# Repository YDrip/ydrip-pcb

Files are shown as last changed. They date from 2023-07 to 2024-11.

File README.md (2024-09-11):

# Open-Source Water Meter Hardware Design

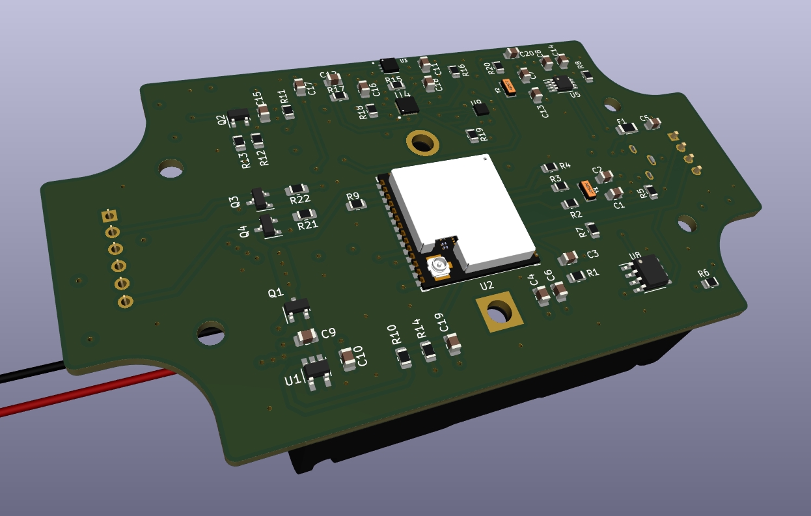
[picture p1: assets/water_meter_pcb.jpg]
PCB ICs

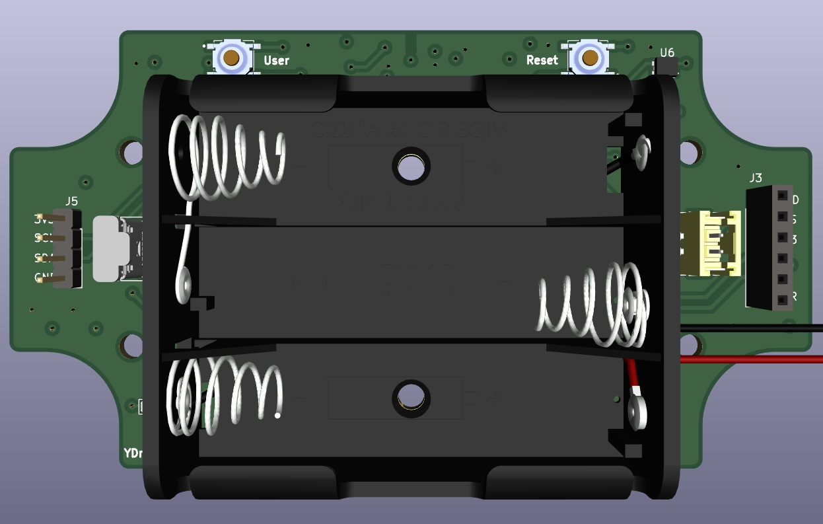
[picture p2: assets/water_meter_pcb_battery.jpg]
PCB Battery


## Description

This repository contains the open-source hardware design files for a water meter. The design was created using KiCad 6.

## Features

- High-precision water metering
- Low power consumption
- Compact and cost-effective design
- Compatible with standard water metering infrastructure
- Customizable digital logic

## Details

Panalization command

```bash
	kikit panelize \
	--layout 'grid; rows: 2; cols: 2; space: 2mm' \
	--tabs 'fixed; width: 8mm; vcount: 2; hcount: 1'\
	--cuts 'mousebites; drill: 0.5mm; spacing: 1mm; offset: 0.2mm; prolong: 0.5mm'\
	--framing 'frame; width: 5mm; space: 3mm;'\
	--copperfill solid\
	--post 'millradius: 1mm;' water_meter.kicad_pcb panel.kicad_pcb
```

## License

This project is licensed under the CERN Open Hardware Licence Version 2 - Weakly Reciprocal. Please see the `LICENSE.txt` file for more details.

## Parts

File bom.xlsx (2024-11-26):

Electronics
designator | quantity | value | pack | mpn | Digikey PN | Mouser PN | mount_type
C1, C13, C2, C7 | 4 | 22pF | C_0805_2012Metric | CL21C220JBANNNC | 1276-1047-1-ND | 187-CL21C220JBANNNC | smt
C10, C3, C9 | 3 | 1uF | C_0805_2012Metric | CL21B105KAFNNNE | 1276-1066-1-ND | 187-CL21B105KAFNNNG | smt
C11, C12 | 2 | 100pF | C_0805_2012Metric | CL21C101JBANNND | CL21C101JBANNND-ND | 187-CL21C101JBANNND | smt
C14, C15, C17, C18, C19, C6, C16, C20 | 8 | 0.1uF | C_0805_2012Metric | 08053C104KAT4A | 478-KGM21NR71E104KMCT-ND | 581-08053C104KAT4A | smt
C4 | 1 | 22uF | C_0805_2012Metric | CL21A226MQQNNNE | 1276-1100-1-ND | 187-CL21A226MQQNNNE | smt
C5, C8 | 2 | 10uF | C_0805_2012Metric | CL21A106KPFNNNG | 1276-6456-1-ND | 187-CL21A106KPFNNNG | smt
J1 | 1 | Conn_01x02_Female | JST_PH_B2B-PH-SM4-TB_1x02-1MP_P2.00mm_Vertical | B2B-PH-SM4-TB | 455-B2B-PH-SM4-TBCT-ND | 306-B2BPHSM4TBLFSN | smt
J3 | 1 | Conn_01x06_Male | PinSocket_1x06_P2.54mm_Vertical | PH1-06-UA | 2057-PH1-06-UA-ND | 737-PH1-06-UA | tht
J4 | 1 | USB_B_Micro | USB_Micro-B_Molex-105133-0001 | 105133-0001 | WM9734CT-ND | 538-105133-0001 | smt
J5 | 1 | Conn_01x04_Male | PinHeader_1x04_P2.54mm_Vertical | PH1-04-UA | 2057-PH1-04-UA-ND | 737-PH1-04-UA | tht
J6 | 1 | 2465 | 2465 | 2465 | 36-2465-ND | 534-2465 | tht
Q1, Q2 | 2 | BSS84 | SOT-23 | BSS84LT1G | BSS84LT1GOSCT-ND | 863-BSS84LT1G | smt
Q3, Q4 | 2 | MMBT3904 | SOT-23 | MMBT3904LT1G | MMBT3904LT1GOSCT-ND | 863-MMBT3904LT1G | smt
R1, R12, R20, R21, R22 | 4 | 10k | R_0805_2012Metric | CRCW080510K0FKEAC | 541-3976-1-ND | 71-CRCW080510K0FKEAC | smt
R11 | 1 | 2k | R_0805_2012Metric | CRCW08052K00FKEAC | 541-4134-1-ND | 71-CRCW08052K00FKEAC | smt
R13 | 1 | 510R | R_0805_2012Metric | CRCW0805510RFKEAC | 541-510CCT-ND | 71-CRCW0805510RFKEAC | smt
R8 | 1 | 100k | R_0805_2012Metric | CRCW0805100KJNEAC | 541-4164-1-ND | 71-CRCW0805100KJNEAC | smt
R16, R17 | 2 | 20k | R_0805_2012Metric | CRCW080520K0FKEAC | 541-4133-1-ND | 71-CRCW080520K0FKEAC | smt
R18, R19, R10, R14 | 4 | 1M | R_0805_2012Metric | CRCW08051M00FKEA | 541-1.00MCCT-ND | 71-CRCW08051M00FKEAC | smt
R2, R3 | 2 | 0 | R_0805_2012Metric | RC0805FR-070RL | 311-0.0CRCT-ND | 603-RC0805FR-070RL | smt
R5, R7 | 2 | 4.7k | R_0805_2012Metric | CRCW08054R70FKEA | 541-4.70CCCT-ND | 71-CRCW0805-4.7-E3 | smt
S1, S2 | 2 | PTS526_SK15_SMTR2_LFS | PTS526SK15SMTR2LFS | PTS526 SK15 SMTR2 LFS | CKN12221-1-ND | 611-PTS526SK15SMR2L | smt
U1 | 1 | RT9080-33GJ5 | SOT-23-5_HandSoldering | RT9080-33GJ5 | 1028-1509-1-ND | 835-RT9080-33GJ5 | smt
U2 | 1 | ESP32-S3-WROOM-1 | ESP32-S3-WROOM-1U | ESP32-S3-WROOM-1U-N16 | 1965-ESP32-S3-WROOM-1U-N16CT-ND | 356-ESP32S3WROM1UN16 | smt
U3 | 1 | ALT021-10E | SON65P250X250X80-7N | ALT021-10E | 391-ALT021-10E-TR7CT-ND | N/A | tht
U4 | 1 | SLG47004V | STQFN-24-3.0X3.0-A | SLG47004V | 1695-SLG47004VCT-ND | 724-SLG47004V | smt
U5 | 1 | PCF8563TS | MSOP-8_3x3mm_P0.65mm | PCF8563TS/5,118 | 568-6651-1-ND | 771-PCF8563TS/5118 | smt
U6 | 1 | IN-PI22TAT5R5G5B | INPI22TAT5R5G5B | IN-PI22TAT5R5G5B | 1830-1207-1-ND | 743-IN-PI22TAT5R5G5B | smt
U8 | 1 | MB85RC64TA | SOIC-8_3.9x4.9mm_P1.27mm | MB85RC64TAPNF-G-BDERE1 | 865-1274-1-ND | 249-85C64TAPNFGBDR1 | smt
U9 | 1 | SLG88103V | SLG88103V | SLG88103V | 1695-SLG88103VCT-ND | 402-SLG88103V | smt
Y1, Y2 | 2 | ABS07-32.768KHZ-T | XTAL_ABS07-32.768KHZ-T | ABS07-32.768KHZ-T | 535-9542-1-ND | 815-ABS07-32.768KHZT | smt
~~R4, R9~~ | ~~1~~ | ~~10K~~ | ~~R_0805_2012Metric~~ |  |  |  | ~~smt~~
~~D2~~ | ~~1~~ | ~~LED~~ | ~~LED_0805_2012Metric~~ |  |  |  | ~~smt~~
~~F1~~ | ~~1~~ | ~~MF-NSMF110~~ | ~~Fuse_1206_3216Metric~~ |  |  |  | ~~smt~~
~~R6,~~ | ~~1~~ | ~~2~~ | ~~4.7k~~
~~R15~~ | ~~1~~ | ~~100k~~ | ~~R_0805_2012Metric~~ | ~~CRCW0805100KJNEAC~~ | ~~541-4164-1-ND~~ | ~~71-CRCW0805100KJNEAC ~~ | ~~smt~~
Accessories
 |  |  | SMA Connector | CAB.721 | 931-1189-ND | 960-CAB721
 |  |  | RF Antenna | GW.34.5153 | 931-GW.34.5153-ND | 960-GW.34.5153
 |  |  | PCB Antenna | YF0023CA | 2958-YF0023CACT-ND

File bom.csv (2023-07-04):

Source: | /home/nabil/Projects/water_meter/hardware/water_meter/water_meter.kicad_sch
Date: | Tue 11 Apr 2023 01:28:04 PM EDT
Tool: | Eeschema 6.0.11-2627ca5db0~126~ubuntu20.04.1
Generator: | /usr/share/kicad/plugins/bom_csv_grouped_by_value.py
Component Count: | 52
Collated Components:
Item | Qty | Reference(s) | Value | Footprint | Digikey Part Number | Mouser Part Number
1 | 4 | C1, C2, C7, C13 | 22pF | Capacitor_SMD:C_0805_2012Metric
2 | 3 | C3, C9, C10 | 1uF | Capacitor_SMD:C_0805_2012Metric
3 | 1 | C4 | 22uF | Capacitor_SMD:C_0805_2012Metric
4 | 2 | C5, C8 | 10uF | Capacitor_SMD:C_0805_2012Metric
5 | 4 | C6, C14, C15, C16 | 0.1uF | Capacitor_SMD:C_0805_2012Metric
6 | 2 | C11, C12 | 100pF | Capacitor_SMD:C_0805_2012Metric
7 | 0 | D2 | LED | LED_SMD:LED_0805_2012Metric
8 | 0 | F1 | MF-NSMF110 | Fuse:Fuse_1206_3216Metric |  | 652-MF-NSMF110-2
10 | 1 | J1 | 2464 | Nabil:2464 |  | 534-2464
11 | 1 | J3 | Conn_01x06_Male | Connector_PinSocket_2.54mm:PinSocket_1x06_P2.54mm_Vertical
12 | 0 | J4 | USB_Micro-10118193-0001LF | Nabil:FCI_10118193-0001LF |  | 649-10118193-0001LF
13 | 1 | J5 | Conn_01x02_Male | Jumper:SolderJumper-2_P1.3mm_Bridged_Pad1.0x1.5mm
14 | 1 | J8 | Conn_01x02_Male | Connector_PinSocket_2.54mm:PinSocket_1x02_P2.54mm_Vertical
15 | 2 | Q1, Q2 | BSS84 | Package_TO_SOT_SMD:SOT-23 |  | 771-BSS84AK215
16 | 2 | R1, R9 | 10k | Resistor_SMD:R_0805_2012Metric
17 | 2 | R2, R3 | 0 | Resistor_SMD:R_0805_2012Metric
18 | 1 | R4 | 10K | Resistor_SMD:R_0805_2012Metric
19 | 2 | R5, R7 | 4.7k | Resistor_SMD:R_0805_2012Metric
20 | 1 | R6 | 5.1K | Resistor_SMD:R_0805_2012Metric
21 | 2 | R8, R10 | 100k | Resistor_SMD:R_0805_2012Metric
22 | 3 | R11, R12, R13 | 500R | Resistor_SMD:R_0805_2012Metric
24 | 1 | U2 | ESP32-S3-WROOM-1 | Espressif:ESP32-S3-WROOM-1U |  | 356-ESP32S3WROM1UN16
26 | 1 | U4 | SLG46826G | Nabil:SOP65P640X120-20N |  | 724-SLG46826G
27 | 1 | U5 | PCF8563TS | Package_SO:MSOP-8_3x3mm_P0.65mm |  | 771-PCF8563TS/5118
28 | 1 | U6 | IN-PI22TAT5R5G5B | Nabil:INPI22TAT5R5G5B |  | 743-IN-PI22TAT5R5G5B
29 | 1 | U7 | 10413_lens | Nabil:10414_Lens |  | 962-10413
30 | 1 | U8 | MB85RC64TA | Package_SO:SOIC-8_3.9x4.9mm_P1.27mm |  | 249-85C64TAPNFGBDR1
31 | 2 | Y1, Y2 | ABS07-32.768KHZ-T | Nabil:XTAL_ABS07-32.768KHZ-T |  | 815-ABS07-32.768KHZT
 | 1 |  | SMA Antenna CAB.721 |  |  | 960-CAB721
 |  |  | Pulse Electronics Antenna W1030 |  |  | 673-W1030

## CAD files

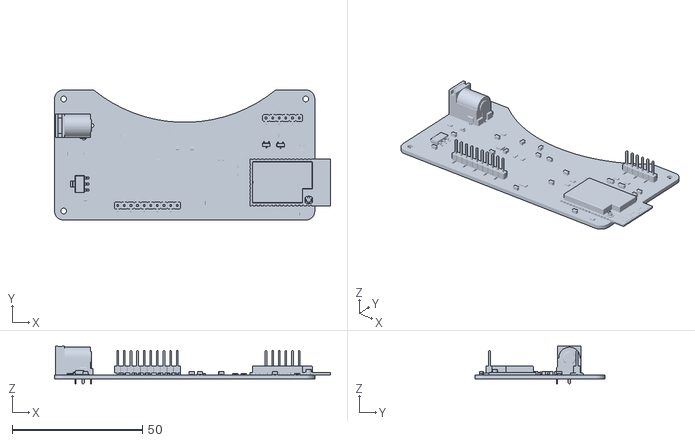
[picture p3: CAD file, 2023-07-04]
water_meter.stl
106.0 x 50.0 x 14.5

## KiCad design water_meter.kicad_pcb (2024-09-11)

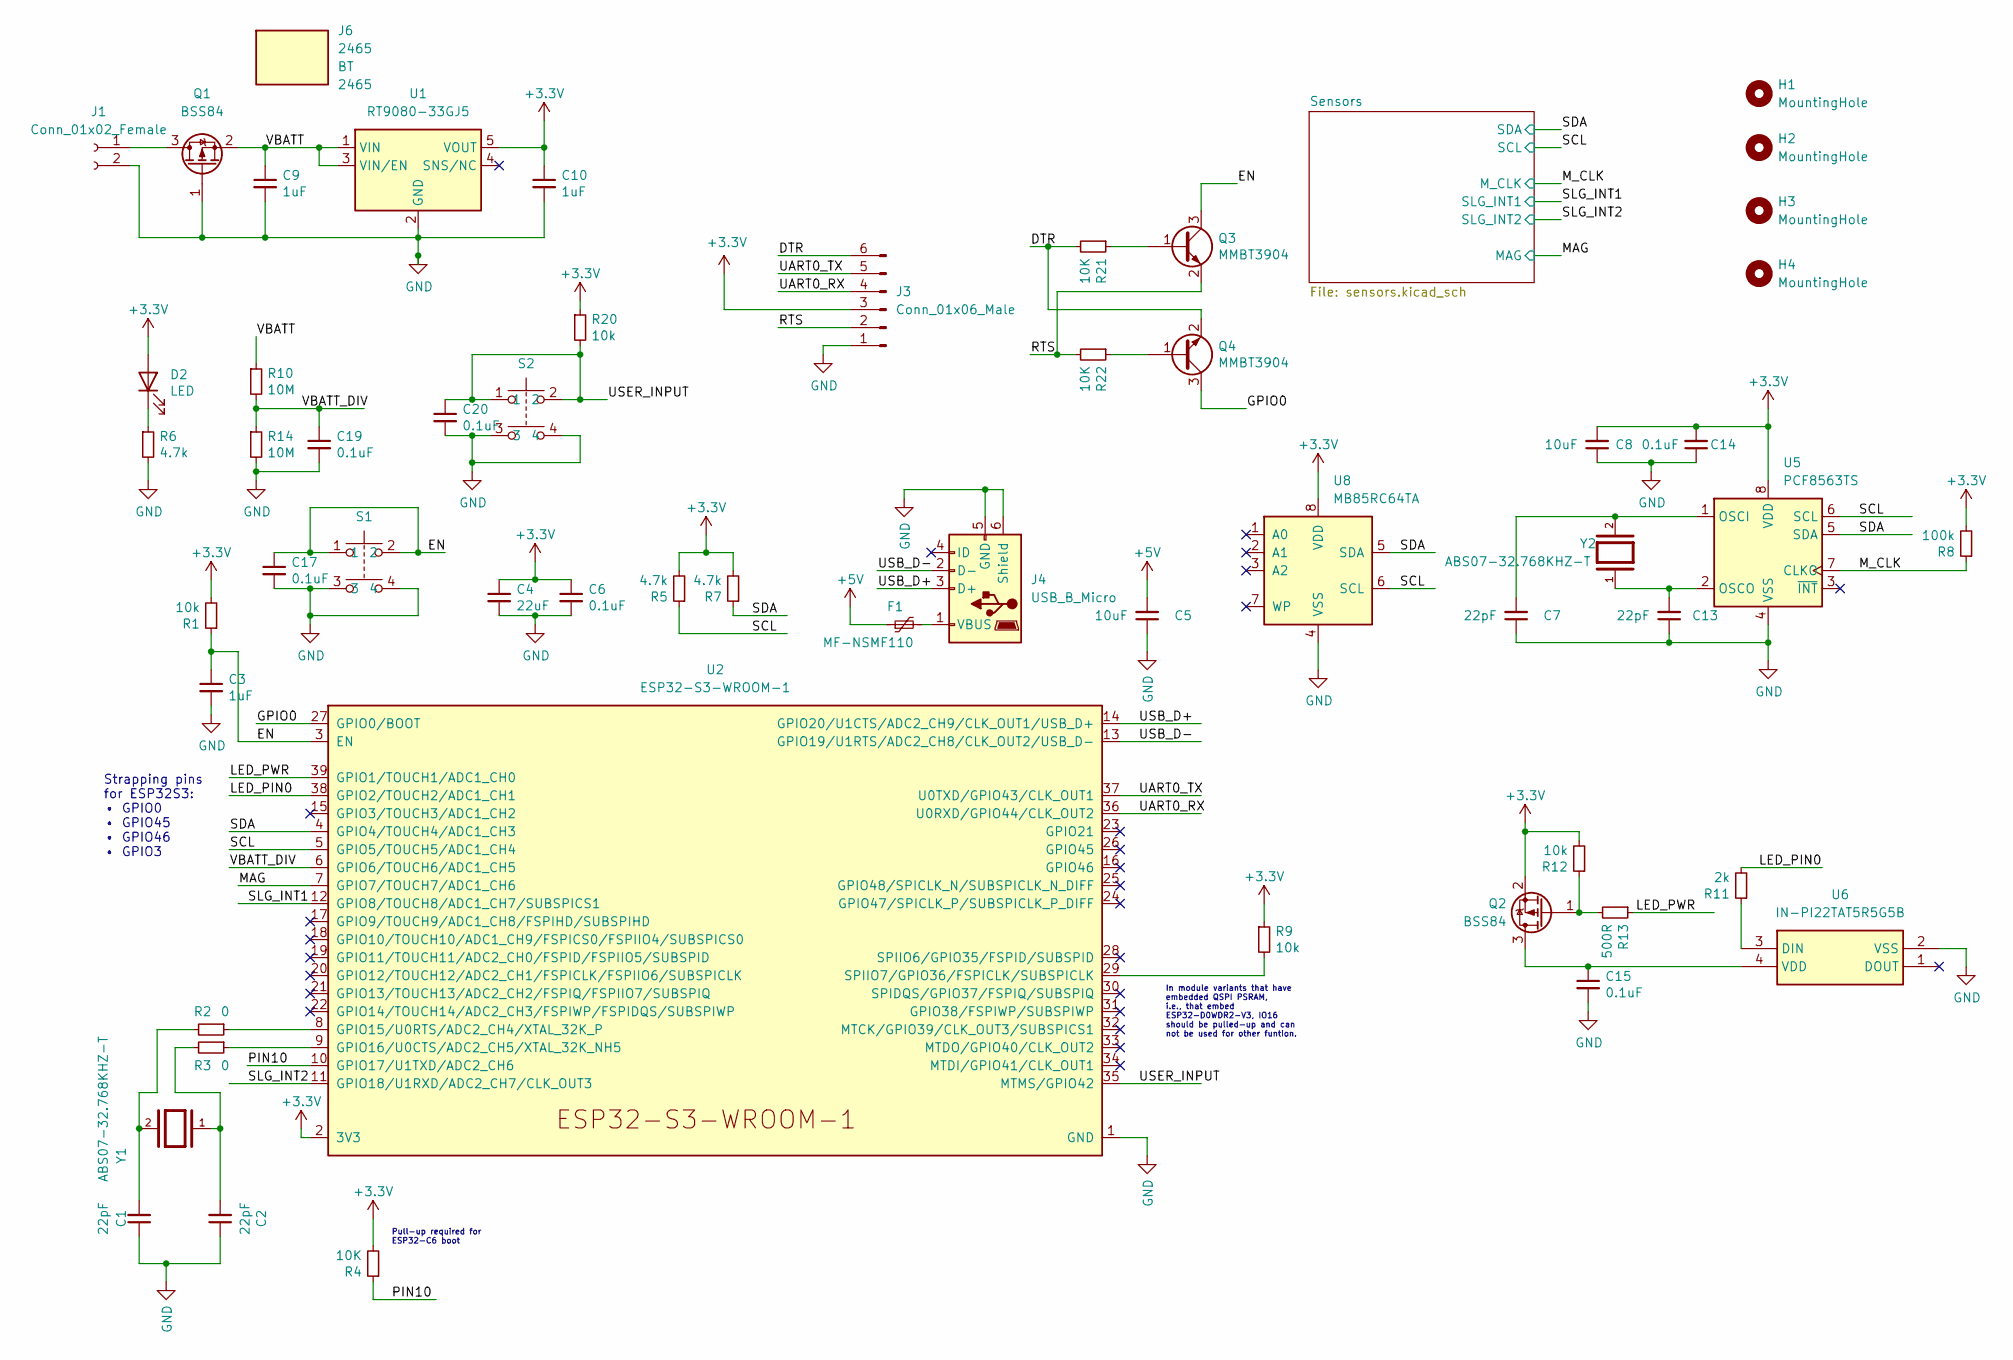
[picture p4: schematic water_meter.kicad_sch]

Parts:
C1, C2, C7, C13: 22pF; C_0805_2012Metric
C3, C9, C10: 1uF; C_0805_2012Metric
C4: 22uF; C_0805_2012Metric
C5, C8: 10uF; C_0805_2012Metric
C6, C14, C15, C17, C19, C20: 0.1uF; C_0805_2012Metric
D2: LED; LED_0805_2012Metric
F1: MF-NSMF110; Fuse_1206_3216Metric; Mouser Part Number 652-MF-NSMF110-2
H1, H2, H3, H4: MountingHole; MountingHole_3.2mm_M3
J1: Conn_01x02_Female; JST_PH_B2B-PH-SM4-TB_1x02-1MP_P2.00mm_Vertical
J3: Conn_01x06_Male; PinSocket_1x06_P2.54mm_Vertical
J4: USB_B_Micro; USB_Micro-B_Molex-105133-0001
J6: 2465; Manufacturer_Part_Number 2465; Mouser Part Number 534-2465
Q1, Q2: BSS84; SOT-23; Mouser Part Number 771-BSS84AK215
Q3, Q4: MMBT3904; SOT-23
R1, R9, R12, R20: 10k; R_0805_2012Metric
R2, R3: 0; R_0805_2012Metric
R4: 10K; R_0805_2012Metric
R5, R6, R7: 4.7k; R_0805_2012Metric
R8: 100k; R_0805_2012Metric
R10, R14: 10M; R_0805_2012Metric
R11: 2k; R_0805_2012Metric
R13: 500R; R_0805_2012Metric
R21, R22: 10K; R_0805_2012Metric_Pad1.20x1.40mm_HandSolder
S1, S2: PTS526_SK15_SMTR2_LFS; PTS526SK15SMTR2LFS; Manufacturer_Part_Number PTS526 SK15 SMTR2 LFS; Mouser Part Number 611-PTS526SK15SMR2L
U1: RT9080-33GJ5; SOT-23-5_HandSoldering; Digikey Part Number 1028-1509-1-ND
U2: ESP32-S3-WROOM-1; ESP32-S3-WROOM-1U; Mouser Part Number 356-ESP32S3WROM1UN16
U5: PCF8563TS; MSOP-8_3x3mm_P0.65mm; Mouser Part Number 771-PCF8563TS/5118
U6: IN-PI22TAT5R5G5B; INPI22TAT5R5G5B; Manufacturer_Part_Number IN-PI22TAT5R5G5B; Mouser Part Number 743-IN-PI22TAT5R5G5B
U8: MB85RC64TA; SOIC-8_3.9x4.9mm_P1.27mm; Mouser Part Number 249-85C64TAPNFGBDR1
Y1, Y2: ABS07-32.768KHZ-T; XTAL_ABS07-32.768KHZ-T; PARTREV 08.19.15; Mouser Part Number 815-ABS07-32.768KHZT

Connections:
+3V3: C4.1, C6.1, C8.2, C10.1, C14.2, D2.2 (A), J3.3, Q2.2 (S), R1.2, R4.2, R5.2, R7.2, R8.2, R9.1, R12.2, R20.1, U1.5 (VOUT), U2.2 (3V3), U5.8 (VDD), U8.8 (VDD); also elsewhere on the board
+5V: C5.2, F1.1
/DTR: J3.6, Q4.2 (E), R21.2
/EN: C3.1, C17.1, Q3.3 (C), R1.1, S1.1, S1.2, U2.3 (EN)
/GPIO0: Q4.3 (C), U2.27 (GPIO0/BOOT)
/LED_PIN0: R11.2, U2.38 (GPIO2/TOUCH2/ADC1_CH1)
/LED_PWR: R13.1, U2.39 (GPIO1/TOUCH1/ADC1_CH0)
/MAG: U2.7 (GPIO7/TOUCH7/ADC1_CH6); also elsewhere on the board
/M_CLK: R8.1, U5.7 (CLKO); also elsewhere on the board
/PIN10: R4.1, U2.10 (GPIO17/U1TXD/ADC2_CH6)
/RTS: J3.2, Q3.2 (E), R22.2
/SCL: R5.1, U2.5 (GPIO5/TOUCH5/ADC1_CH4), U5.6 (SCL), U8.6 (SCL); also elsewhere on the board
/SDA: R7.1, U2.4 (GPIO4/TOUCH4/ADC1_CH3), U5.5 (SDA), U8.5 (SDA); also elsewhere on the board
/SLG_INT1: U2.12 (GPIO8/TOUCH8/ADC1_CH7/SUBSPICS1); also elsewhere on the board
/SLG_INT2: U2.11 (GPIO18/U1RXD/ADC2_CH7/CLK_OUT3); also elsewhere on the board
/UART0_RX: J3.4, U2.36 (U0RXD/GPIO44/CLK_OUT2)
/UART0_TX: J3.5, U2.37 (U0TXD/GPIO43/CLK_OUT1)
/USB_D+: J4.3 (D+), U2.14 (GPIO20/U1CTS/ADC2_CH9/CLK_OUT1/USB_D+)
/USB_D-: J4.2 (D-), U2.13 (GPIO19/U1RTS/ADC2_CH8/CLK_OUT2/USB_D-)
/USER_INPUT: C20.1, R20.2, S2.1, S2.2, U2.35 (MTMS/GPIO42)
/VBATT: C9.1, Q1.2 (S), R10.1, U1.1 (VIN), U1.3 (VIN/EN)
/VBATT_DIV: C19.1, R10.2, R14.1, U2.6 (GPIO6/TOUCH6/ADC1_CH5)
GND: C1.1, C2.1, C3.2, C4.2, C5.1, C6.2, C7.1, C8.1, C9.2, C10.2, C13.1, C14.1, C15.2, C17.2, C19.2, C20.2, J1.2, J3.1, J4.5 (GND), J4.6 (Shield), Q1.1 (G), R6.2, R14.2, S1.3, S1.4, S2.3, S2.4, U1.2 (GND), U2.1 (GND), U2.40 (GND), U2.41 (GND), U5.4 (VSS), U6.2 (VSS), U8.4 (VSS); also elsewhere on the board
unnamed: C1.2, R2.2, Y1.2
unnamed: C2.2, R3.2, Y1.1
unnamed: C7.2, U5.1 (OSCI), Y2.2
unnamed: C13.2, U5.2 (OSCO), Y2.1
unnamed: C15.1, Q2.3 (D), U6.4 (VDD)
unnamed: D2.1 (K), R6.1
unnamed: F1.2, J4.1 (VBUS)
unnamed: J1.1, Q1.3 (D)
unnamed: Q2.1 (G), R12.1, R13.2
unnamed: Q3.1 (B), R21.1
unnamed: Q4.1 (B), R22.1
unnamed: R2.1, U2.8 (GPIO15/U0RTS/ADC2_CH4/XTAL_32K_P)
unnamed: R3.1, U2.9 (GPIO16/U0CTS/ADC2_CH5/XTAL_32K_NH5)
unnamed: R9.2, U2.29 (SPIIO7/GPIO36/FSPICLK/SUBSPICLK)
unnamed: R11.1, U6.3 (DIN)

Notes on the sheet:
In module variants that have embedded QSPI PSRAM, i.e., that embed ESP32-D0WDR2-V3, IO16 should be pulled-up and can not be used for other funtion.
Pull-up required for ESP32-C6 boot
Strapping pins for ESP32S3: • GPIO0 • GPIO45 • GPIO46 • GPIO3

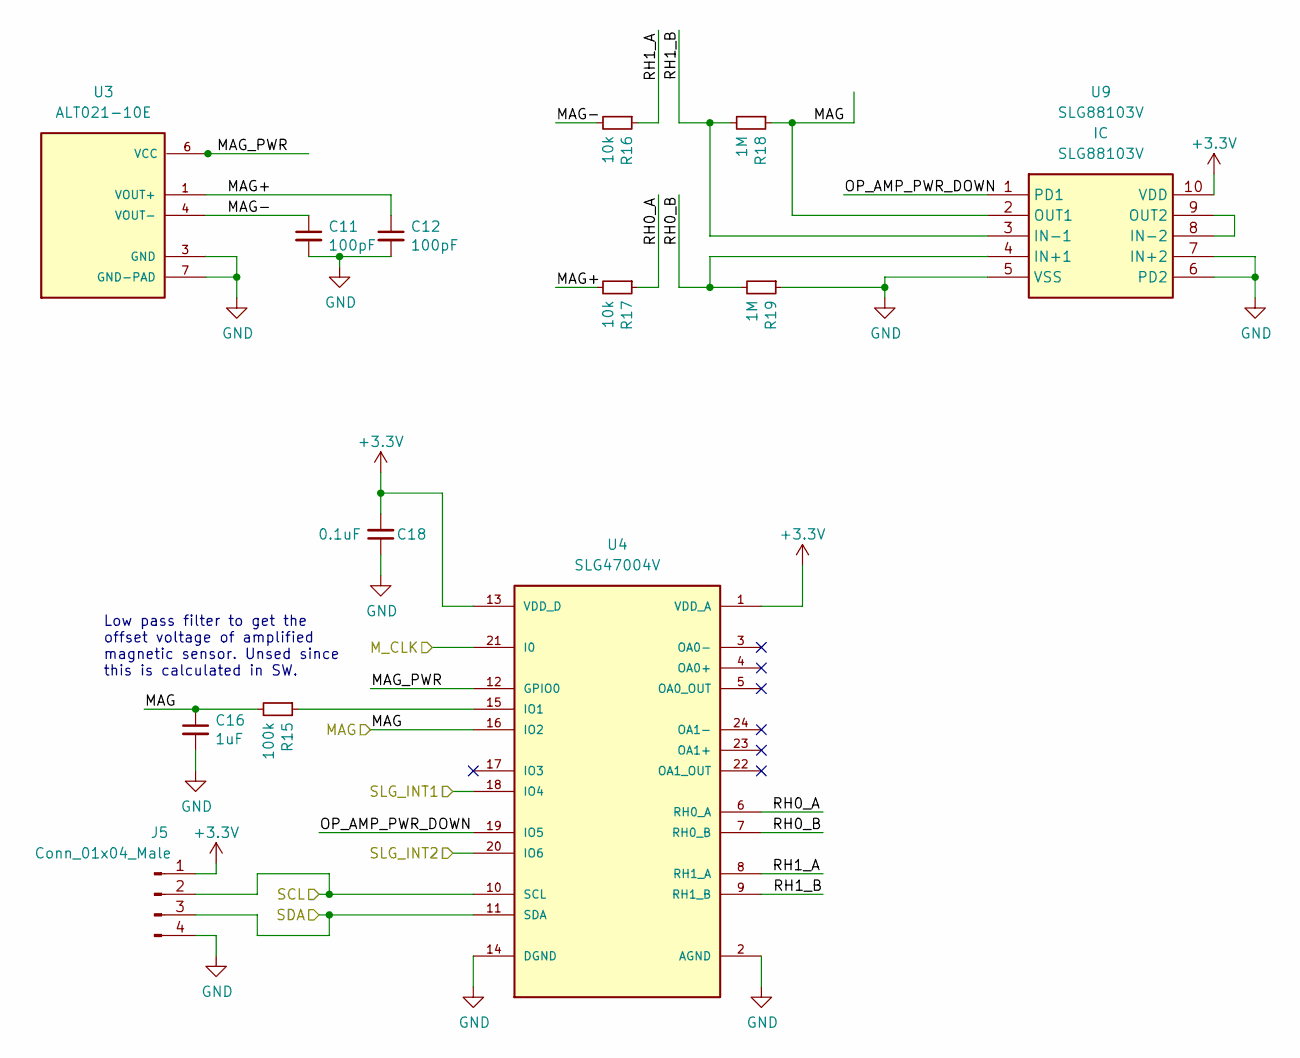
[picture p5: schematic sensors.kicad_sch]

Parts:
C11, C12: 100pF; C_0805_2012Metric
C16: 1uF; C_0805_2012Metric
C18: 0.1uF; C_0805_2012Metric
J5: Conn_01x04_Male; PinHeader_1x04_P2.54mm_Vertical
R15: 100k; R_0805_2012Metric
R16, R17: 10k; R_0805_2012Metric
R18, R19: 1M; R_0805_2012Metric
U3: ALT021-10E; SON65P250X250X80-7N; PARTREV November 2019
U4: SLG47004V; STQFN-24-3.0X3.0-A
U9: SLG88103V; Manufacturer_Part_Number SLG88103V

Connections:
+3V3: C18.2, J5.1, U4.1 (VDD_A), U4.13 (VDD_D), U9.10 (VDD); also elsewhere on the board
/MAG: C16.1, R15.2, R18.1, U4.16 (IO2), U9.2 (OUT1); also elsewhere on the board
/M_CLK: U4.21 (I0); also elsewhere on the board
/SCL: J5.2, U4.10 (SCL); also elsewhere on the board
/SDA: J5.3, U4.11 (SDA); also elsewhere on the board
/SLG_INT1: U4.18 (IO4); also elsewhere on the board
/SLG_INT2: U4.20 (IO6); also elsewhere on the board
/Sensors/MAG+: C12.1, R17.2, U3.1 (VOUT+)
/Sensors/MAG-: C11.1, R16.2, U3.4 (VOUT-)
/Sensors/MAG_PWR: U3.6 (VCC), U4.12 (GPIO0)
/Sensors/OP_AMP_PWR_DOWN: U4.19 (IO5), U9.1 (PD1)
/Sensors/RH0_A: R17.1, U4.6 (RH0_A)
/Sensors/RH0_B: R19.2, U4.7 (RH0_B), U9.4 (IN+1)
/Sensors/RH1_A: R16.1, U4.8 (RH1_A)
/Sensors/RH1_B: R18.2, U4.9 (RH1_B), U9.3 (IN-1)
GND: C11.2, C12.2, C16.2, C18.1, J5.4, R19.1, U3.3 (GND), U3.7 (GND-PAD), U4.2 (AGND), U4.14 (DGND), U9.5 (VSS), U9.6 (PD2), U9.7 (IN+2); also elsewhere on the board
unnamed: R15.1, U4.15 (IO1)
unnamed: U9.8 (IN-2), U9.9 (OUT2)

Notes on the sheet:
Low pass filter to get the offset voltage of amplified magnetic sensor. Unsed since this is calculated in SW.

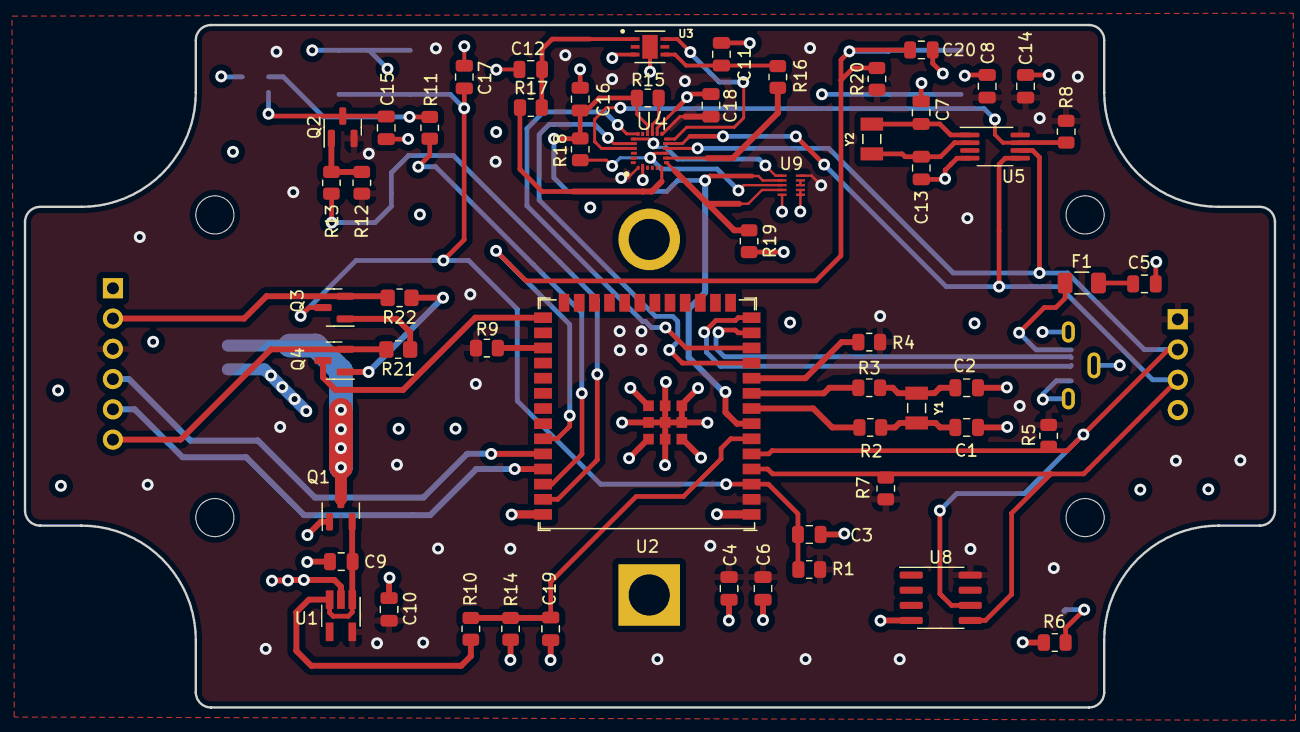
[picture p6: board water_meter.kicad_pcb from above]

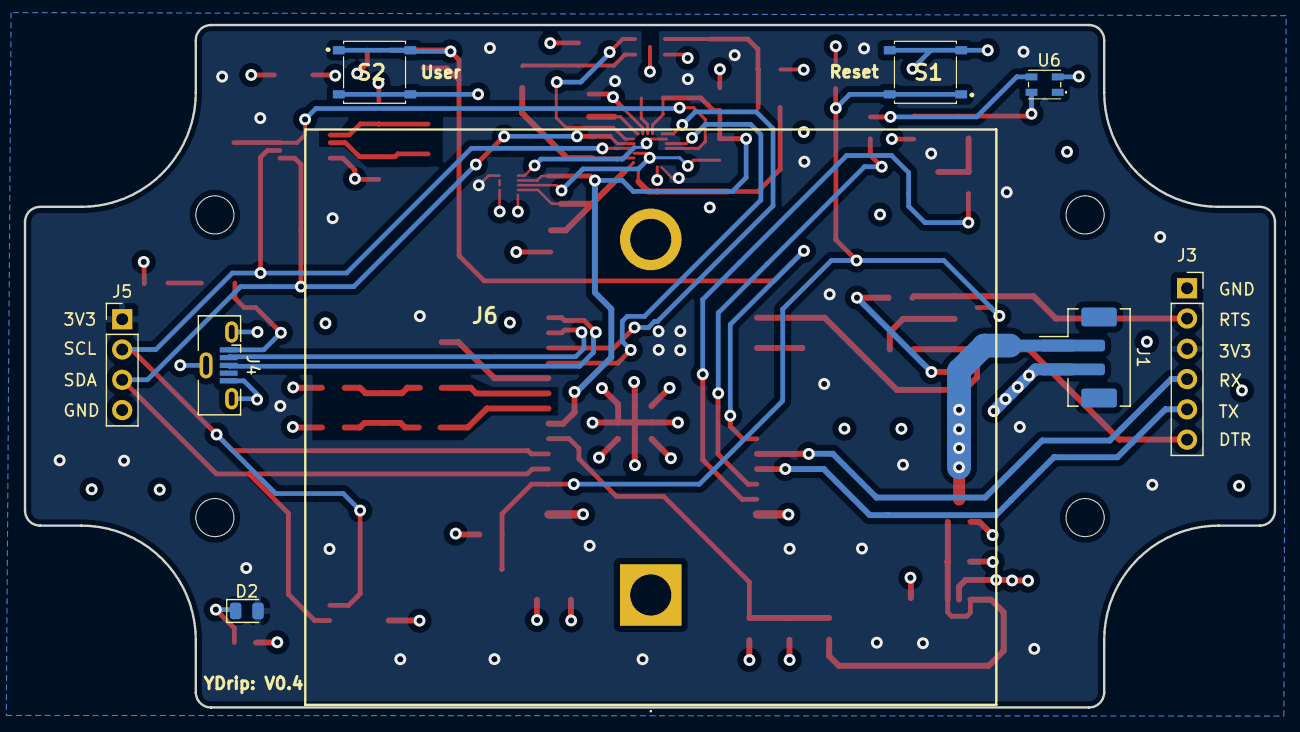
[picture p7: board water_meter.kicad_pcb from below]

Board: 4 copper layers, 104.9 x 57.3 mm, 69 parts (9 on the bottom side), 48 nets.

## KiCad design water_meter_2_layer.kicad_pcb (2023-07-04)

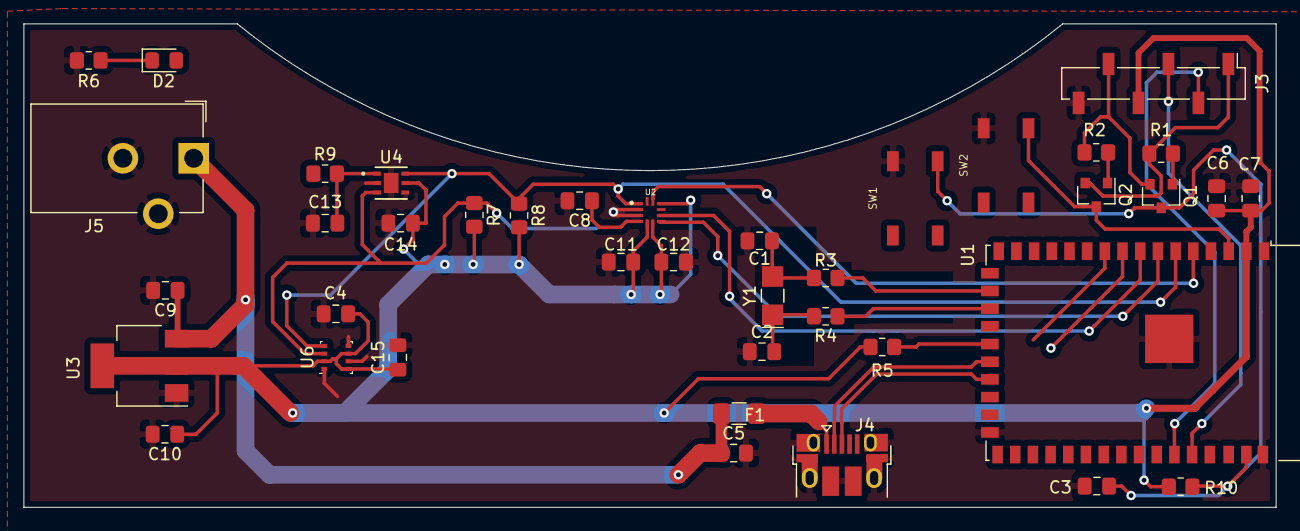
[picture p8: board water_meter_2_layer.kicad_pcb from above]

Board: 2 copper layers, 106.2 x 41.0 mm, 40 parts (0 on the bottom side), 26 nets.

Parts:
C1, C2, C6: 22uF; C_0805_2012Metric_Pad1.18x1.45mm_HandSolder
C3, C9, C12, C13, C14: 1uF; C_0805_2012Metric_Pad1.18x1.45mm_HandSolder
C4, C8, C11, C15: 100nF; C_0805_2012Metric_Pad1.18x1.45mm_HandSolder
C5: 10uF/25V(20%); C_0805_2012Metric_Pad1.18x1.45mm_HandSolder
C7: 0.1uF; C_0805_2012Metric_Pad1.18x1.45mm_HandSolder
C10: 1uF(X5R); C_0805_2012Metric_Pad1.18x1.45mm_HandSolder
D2: LED; LED_0805_2012Metric_Pad1.15x1.40mm_HandSolder
F1: MF-NSMF110; Fuse_1206_3216Metric_Pad1.42x1.75mm_HandSolder
J3: Conn_01x06; PinSocket_1x06_P2.54mm_Vertical_SMD_Pin1Left
J4: USB_B_Micro; USB_Micro-B_Amphenol_10103594-0001LF_Horizontal
J5: Barrel_Jack_Switch; BarrelJack_CUI_PJ-102AH_Horizontal
Q1, Q2: MMBT3904; SOT-23
R1, R2: 10K(1%); R_0805_2012Metric_Pad1.20x1.40mm_HandSolder
R3, R4: 0; R_0805_2012Metric_Pad1.20x1.40mm_HandSolder
R5: 10K; R_0805_2012Metric_Pad1.20x1.40mm_HandSolder
R6: 5.1K; R_0805_2012Metric_Pad1.20x1.40mm_HandSolder
R7, R8: 4.7k; R_0805_2012Metric_Pad1.20x1.40mm_HandSolder
R9: 4.7; R_0805_2012Metric_Pad1.20x1.40mm_HandSolder
R10: 10k(1%); R_0805_2012Metric_Pad1.20x1.40mm_HandSolder
SW1, SW2: TL3342F160QG_TR
U1: ESP32-S2-WROVER
U2: LIS3MDLTR
U3: TLV1117LV33DCYR; SOT-223-3_TabPin2
U4: SGP30-2.5K
U6: BME280; Bosch_LGA-8_2.5x2.5mm_P0.65mm_ClockwisePinNumbering
Y1: 32.768kHz (ESR < 70 kΩ); Crystal_SMD_G8-2Pin_3.2x1.5mm_HandSoldering

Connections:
+3V3: C4.1, C6.1, C7.1, C10.1, C11.1, C12.1, C14.1, C15.1, D2.2, J3.4, R5.1, R7.2, R8.2, R9.1, R10.2, U1.2, U2.5, U2.6, U2.10, U3.2, U4.5, U6.2, U6.6, U6.8
+5V: C5.1, C9.1, F1.1, J5.1, U3.3
DTR: J3.1, Q2.2, R1.2
EN: C3.1, Q1.3, R10.1, SW1.2, U1.41
GND: C1.1, C2.1, C3.2, C4.2, C5.2, C6.2, C7.2, C8.2, C9.2, C10.2, C11.2, C12.2, C13.2, C14.2, C15.2, J3.6, J4.5, J4.6, J5.2, J5.3, R6.2, SW1.4, SW2.4, U1.1, U1.26, U1.42, U1.43, U2.2, U2.3, U2.9, U2.12, U3.1, U4.2, U4.4, U4.7, U6.1, U6.5, U6.7
I2C_CLK: R8.1, U1.6, U2.1, U4.6, U6.4
I2C_DATA: R7.1, U1.5, U2.11, U4.3, U6.3
IO00: Q2.3, SW2.2, U1.3
IO15: R3.1, U1.18
IO16: R4.1, U1.19
IO18: R5.2, U1.21
MAG_DRDY: U1.8, U2.8
MAG_INT: U1.7, U2.7
unnamed: C1.2, R3.2, Y1.2
unnamed: C2.2, R4.2, Y1.1
unnamed: C8.1, U2.4
unnamed: C13.1, R9.2, U4.1
unnamed: D2.1, R6.1
unnamed: F1.2, J4.1
unnamed: Q1.1, R1.1
unnamed: Q2.1, R2.1
RTS: J3.5, Q1.2, R2.2
UART_RX: J3.3, U1.38
UART_TX: J3.2, U1.37
USB_D+: J4.3, U1.23
USB_D-: J4.2, U1.22

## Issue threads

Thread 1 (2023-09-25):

AA battery holder footprint is wrong

YDrip, 2023-09-25:
Positive and negative terminals are reversed. Maybe there is another part number that fits this footprint. If not, fix the footprint.

YDrip, 2024-09-11:
Fixed in 24e5011. Changed to battery holder with wire connector.

Closed 2024-09-11.

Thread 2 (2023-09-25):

V3 Prototype - Low power mode is broken

YDrip, 2023-09-25:
Duty cycling the magnetic sensor produces a distorted amplified waveform.

Potential solution: Duty cycle the SLG88103V amplifier. It's possible the opamp feedback network is biasing the sensor and distorting the signal if the amp is always on. Power the mag sensor then the amplifier may allow the signal to settle before amplification.

Rework required: Connect pin 19 of SLG47004V to pin 1 of the SLG88103V.

ScalpRadar, 2024-09-11:
Fixed in [24e5011](https://github.com/YDrip/ydrip-pcb/commit/24e5011a16618b0e36a29c7a35e67e57f00b404a). Added opamp power down control to programmable logic.

YDrip, 2024-09-11:
Fixed in 24e5011. Added opamp power down control to programmable logic.

Closed 2024-09-11.

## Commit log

2024-09-11 Prototype V0.4 - New board layout for new enclosure - Added user button - Using opamp power down pin to save power
    [PCBWay_bom.csv, PCBWay_positions.csv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]
2024-11-26 Minor bom changes for HW version 0.4 & added missing schematic
    [bom.xlsx, sensors.kicad_sch]

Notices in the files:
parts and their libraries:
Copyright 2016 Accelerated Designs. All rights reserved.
